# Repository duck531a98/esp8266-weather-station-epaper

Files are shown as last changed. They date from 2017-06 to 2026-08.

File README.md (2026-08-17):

# ESP8266 E-Paper Weather Station / Calendar

> [!IMPORTANT]
> ## 4.2-Inch E-Paper Calendar Hardware Project
> **PCB, BOM, enclosure, firmware attachments, and build notes:**<br>
> **[Open the 4.2-inch E-Paper Calendar on OSHWHub](https://oshwhub.com/duck/4-2-cun-mo-shui-ping-ri-li)**

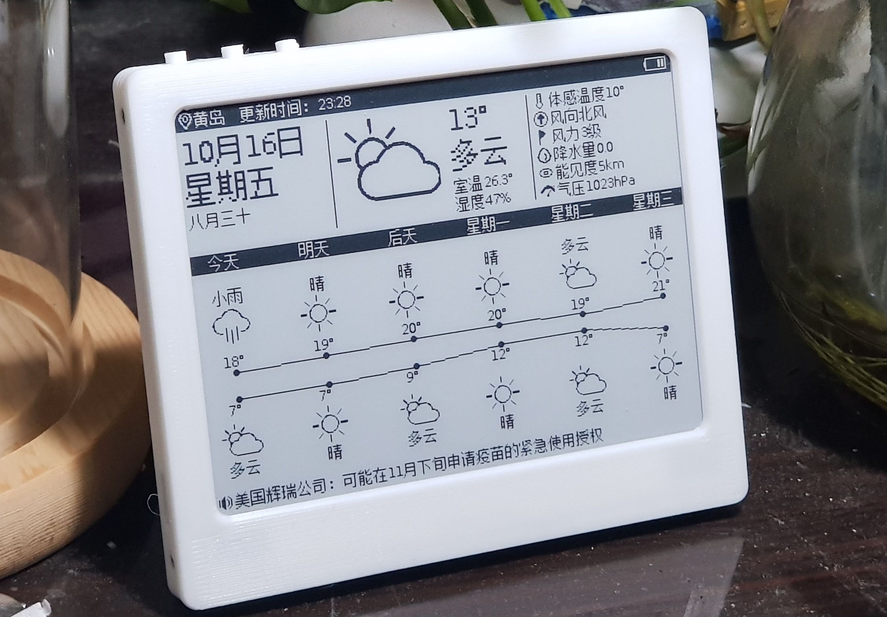
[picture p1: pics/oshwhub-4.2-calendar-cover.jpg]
4.2-inch e-paper weather calendar (https://oshwhub.com/duck/4-2-cun-mo-shui-ping-ri-li)


| 4.2-inch hardware | Multiple display sizes and layouts |
| --- | --- |
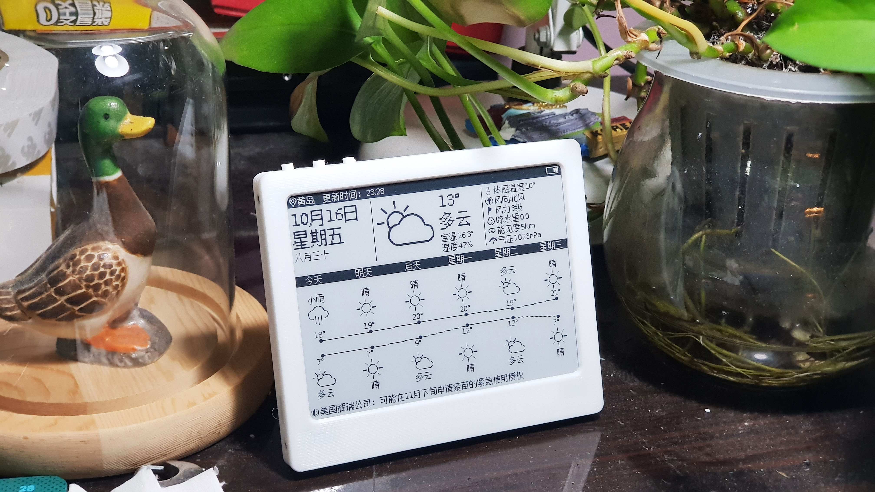
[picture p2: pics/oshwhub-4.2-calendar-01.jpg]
4.2-inch e-paper weather station
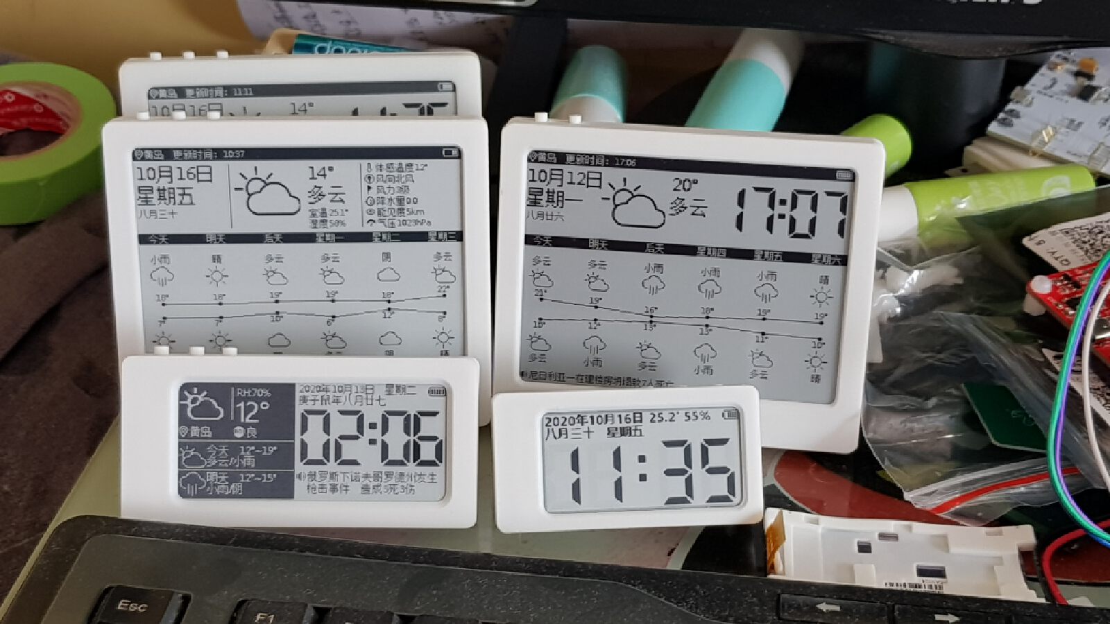
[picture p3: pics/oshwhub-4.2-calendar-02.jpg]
Multiple e-paper weather station builds
|  |  |

This repository contains the latest source code for an ESP8266 NodeMCU v2 e-paper weather station. The device can display weather forecasts, time, date, lunar-calendar information, indoor temperature and humidity, battery status, and custom messages. Partial e-paper refreshes and ESP8266 deep sleep are used to minimize average power consumption.

## Codex-Assisted Improvements

In August 2026, Codex helped review and update the networking, display, low-power, and reliability code. The main changes are:

- **Direct QWeather access:** the firmware now connects directly to QWeather. Each user can configure a personal API Host, API Key, and Location without depending on the original relay server.
- **Bounded network activity:** weather requests, network-time updates, retries, and recovery paths use timeouts and backoff so a failed network or API cannot keep the ESP8266 awake indefinitely.
- **Lower-power wake cycles:** Wi-Fi, SPI, and e-paper high-voltage power sequencing was tightened. Wake cycles that do not require networking can keep RF disabled, while failure and timed-refresh paths spend less time awake.
- **Timed partial-refresh fixes:** the WF32 clock path now preserves sub-second time across deep sleep, corrects clock drift, and separates partial refresh, panel shutdown, and sleep-to-next-minute into a bounded two-stage sequence.
- **Faster rendering:** WF32 frame transfer, framebuffer inversion, text rendering, and XBM raster composition were optimized to reduce per-pixel work, temporary strings, and unnecessary `yield()` calls.
- **Display and settings cleanup:** display paths for several 2.9, 3.2, 4.2, and 5.8-inch panels were normalized. The 4.2-inch date layout and weather-setting validation were also corrected.
- **Regression coverage:** a host-side raster test compares the optimized renderer against the original pixel renderer. All 8,208 XBM drawing cases match byte for byte. The current NodeMCU v2 firmware also compiles with Arduino IDE 1.8.9 and ESP8266 core 3.1.2.

See [`docs/PROJECT.md`](docs/PROJECT.md) for the implementation overview, build environment, and hardware-specific risks.

## Features

- Current weather and multi-day forecast
- Date, weekday, and lunar-calendar display
- Optional time display with partial refresh
- Indoor temperature and humidity display on supported hardware
- Battery-voltage indicator and low-voltage protection
- Configurable weather-update interval and active update window
- Phone-friendly local configuration portal
- Full Unicode font support through fonts stored on the device filesystem
- Custom-message display support
- Deep sleep between updates

## Hardware Projects and Community

- **Recommended 4.2-inch hardware:** [4.2-inch E-Paper Calendar on OSHWHub](https://oshwhub.com/duck/4-2-cun-mo-shui-ping-ri-li)
- **Earlier 2.9-inch PCB:** [ESP8266 E-Paper Weather Station on OSHWHub](https://oshwhub.com/duck/esp8266-weather-station-epaper)
- **Community:** QQ group 556951885

The 4.2-inch project page contains the PCB design, BOM, enclosure archive, firmware attachments, and additional build information.

## Supported Displays

The firmware contains drivers and layouts for several e-paper controllers and panel sizes. Check the manufacturer and model printed on the display flex cable before selecting a screen type in the configuration portal.

- 2.9-inch HINK, WF, DKE, and WFT0000BZ03 variants
- 3.2-inch WF32
- 4.2-inch HINK/OPM, DKE, and WF variants
- 5.8-inch WF58

Waveshare and Good Display sell modules, but the underlying panel may be produced by HINK, WF, DKE, OPM, or another manufacturer. The flex-cable marking is more useful than the module brand when choosing a driver.

## Basic Hardware

1. A supported e-paper panel
2. ESP8266 NodeMCU/Wemos board or the integrated PCB from the hardware project
3. Li-Po battery
4. Low-quiescent-current 3.3 V regulator for battery-powered builds
5. Enclosure appropriate for the selected display size

NodeMCU development boards commonly include an AMS1117 regulator and CP2102 USB-to-serial converter. Their combined quiescent current is too high for an efficient long-term battery build. Use the integrated PCB or another low-power design when battery life matters.

## Display Wiring

| E-Paper Signal | ESP8266 GPIO |
| --- | ---: |
| BUSY | GPIO4 |
| RST | GPIO2 |
| DC | GPIO5 |
| CS | GPIO15 |
| CLK | GPIO14 |
| DIN | GPIO13 |

Connect ESP8266 GPIO16 to RST so the internal deep-sleep timer can wake the chip.

## Build and Upload

- Main sketch: `WeatherStation-epaper-remote.ino`
- Target: ESP8266 NodeMCU v2
- Verified toolchain: Arduino IDE 1.8.9 with ESP8266 core 3.1.2
- Existing build parameters: `.build/build.options.json` in the development workspace

Compile and upload the main sketch with the verified ESP8266 toolchain. Upload the required files from `data/` to the ESP8266 filesystem using a filesystem uploader compatible with ESP8266 core 3.1.2.

The upstream ESP8266 Arduino documentation is available at:

- [ESP8266 Arduino core](https://github.com/esp8266/Arduino)
- [ESP8266 filesystem documentation](https://arduino-esp8266.readthedocs.io/en/latest/filesystem.html)

## Device Configuration

When configuration mode is active, connect a phone or computer to the `Epaper Weather Station` access point and open `http://192.168.4.1/`.

Configure at least:

- Wi-Fi SSID and password
- QWeather API Host
- QWeather API Key
- City or location
- E-paper panel type
- Time-display option
- Weather-update interval and active update window

Wi-Fi credentials and the QWeather API Key are stored on the device. Do not add credentials or generated configuration files to this repository.

## Weather Data

The current firmware connects directly to QWeather over HTTPS. It performs location lookup, current-weather, multi-day forecast, and air-quality requests using the credentials entered in the device portal.

DNS, connection, header, and body reads are bounded. RTC-backed retry state prevents repeated API or network failures from causing long high-power wake cycles.

## Fonts and Localization

The firmware converts UTF-8 strings to Unicode code points for display with `DrawUTF`. Font files are stored in the ESP8266 filesystem. A complete 16-by-16 Unicode font can consume about 2 MB, so builds that need only a limited character set should generate a smaller font.

The original font-generation project is available at [duck531a98/font-generator](https://github.com/duck531a98/font-generator).

## Custom Messages

The firmware retains custom-message display support. The original public relay is no longer included in this repository, so this feature requires a compatible service under your control.

## Low-Power Notes

- Deep-sleep current depends heavily on the regulator, USB-to-serial converter, pull-ups, sensors, and e-paper power circuit used by the hardware.
- E-paper BUSY waits and high-voltage shutdown paths must remain bounded to prevent a failed panel from draining the battery.
- Software time advances across deep sleep using planned sleep duration and is resynchronized during network-enabled wake cycles.
- Weather-only operation can run much longer than minute-by-minute time display because it requires far fewer wake and refresh cycles.

## Changelog

### 2026-08-17

- Imported the latest firmware source code.
- Added direct personal QWeather API configuration.
- Completed the Codex-assisted reliability, rendering, timekeeping, and low-power improvements described above.
- Verified the NodeMCU v2 build and 8,208 raster regression cases.

### 2020-05-14

- Updated the online PCB version. Some older explanations and photos below may no longer represent the current firmware.

### 2015-05-28

1. Changed the voltage-divider resistors from 1 MOhm/300 kOhm to 300 kOhm/100 kOhm (R6/R7).
2. Updated the battery-voltage calculation.
3. Stopped updates and displayed a warning when battery voltage fell below 3.4 V.

Calibrate the ADC for your own board because ESP8266 ADC readings can vary significantly.

## Earlier Project Photos

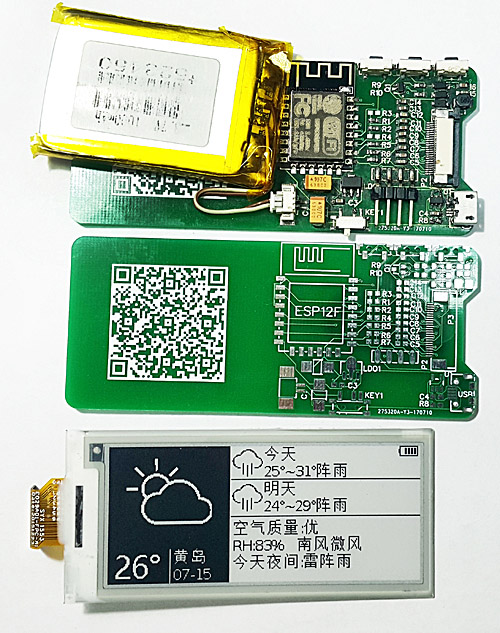
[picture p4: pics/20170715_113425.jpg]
Earlier 2.9-inch weather station


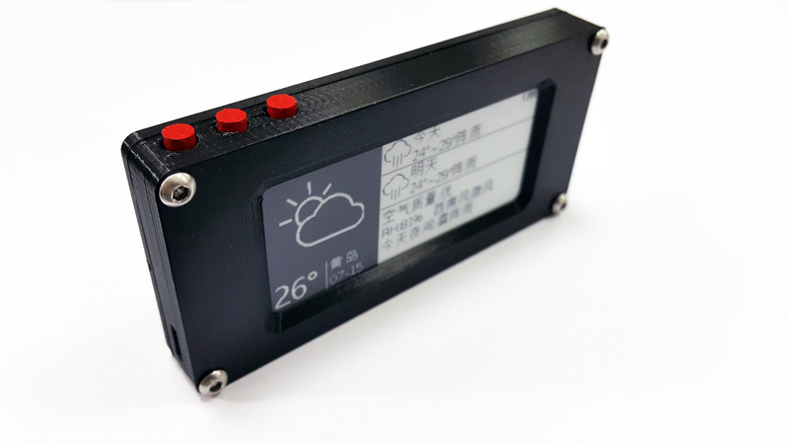
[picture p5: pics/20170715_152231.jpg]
Earlier enclosure and weather display


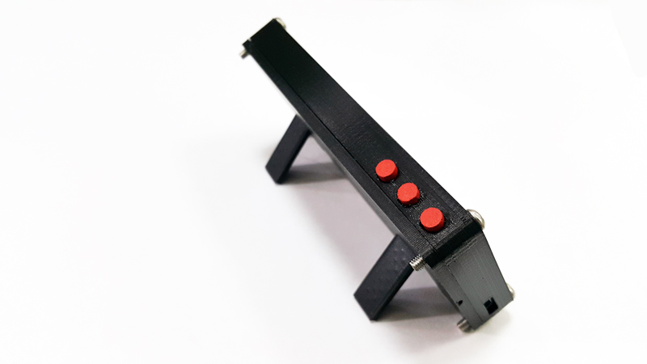
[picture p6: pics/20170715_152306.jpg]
Earlier completed build


## Credits

Thanks to Mike, Daniel, and Fred for their work on ESP8266 weather stations, JSON parsing, e-paper hardware, and the original project ecosystem.

## License

This repository is distributed under the terms in [`LICENSE`](LICENSE).

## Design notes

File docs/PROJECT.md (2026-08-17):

# WeatherStation e-paper remote

> 最后核对日期：2026-08-10

## 项目概览

这是一个运行在 ESP8266 NodeMCU v2 上的低功耗墨水屏天气站固件。设备通过 Wi-Fi 获取和风天气数据与网络时间，在支持的墨水屏上显示天气、空气质量和时间，并通过深睡降低功耗。

## 已确认的实现

- 主程序入口：`WeatherStation-epaper-remote.ino`。
- `TimeClient.cpp` 负责 NTP、HTTP Date 解析、时区换算以及跨深睡的软件时钟推进。
- `heweather.cpp` 负责和风天气网络请求与响应解析。
- `EPD_drive.cpp`、`EPD_drive_gpio.cpp` 负责多个墨水屏型号的初始化、刷新和休眠。
- 配置保存在 LittleFS 与 EEPROM 缓存中；时间、刷新阶段和退避状态使用 ESP8266 RTC 用户内存跨深睡保存。
- WF32（3.2 英寸）在显示时间时采用局刷、短深睡、屏幕关断、再睡至下一分钟的两阶段流程。

## 开发与验证

| 用途 | 方法 |
|---|---|
| 构建 | Arduino IDE 1.8.9 / ESP8266 core 3.1.2；复用 `.build/build.options.json` 中的 NodeMCU v2 FQBN 与库路径 |
| 测试 | `tests/epd_raster_tests.cpp` 使用旧逐点算法作为 oracle，对 XBM 帧缓冲合成做宿主端逐字节差分验证；修改固件后仍需完整编译 |
| 硬件验证 | 烧录连接的 ESP8266，观察启动串口、对应屏幕型号的局刷/全刷路径和网络校时后的显示 |

## 关键约束与风险

- ESP8266 深睡期间无法用 `millis()` 直接测量真实睡眠时长，软件时钟依赖计划睡眠时长并会产生漂移，因此联网周期必须重新校时。
- 屏幕 BUSY、刷新完成和休眠命令属于高功耗敏感路径，故障处理必须保持有界等待并尽量关闭高压电路。
- 设备配置、凭据和生成的固件不应提交到仓库。

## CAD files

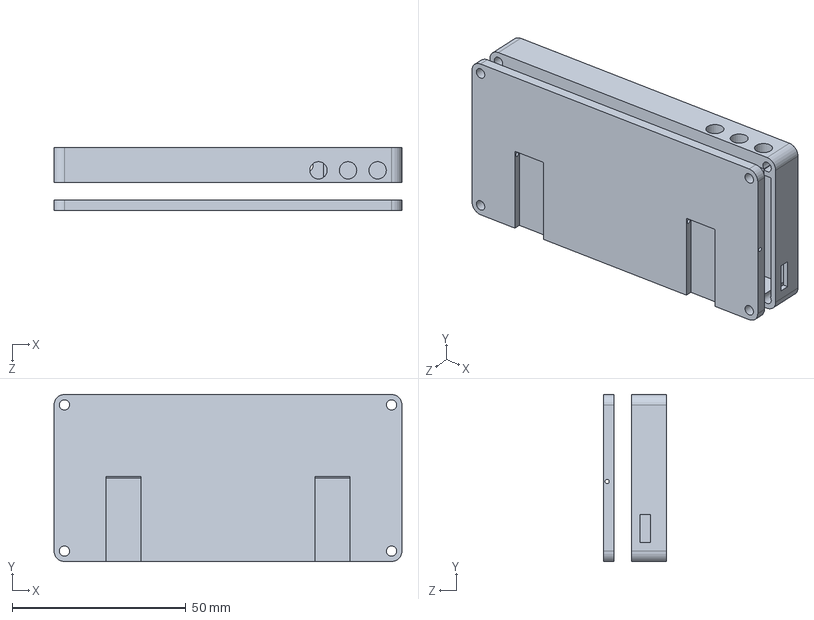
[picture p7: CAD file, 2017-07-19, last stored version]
STL/电纸屏外壳-对称-方形.SLDPRT
100.0 x 48.0 x 18.0 mm

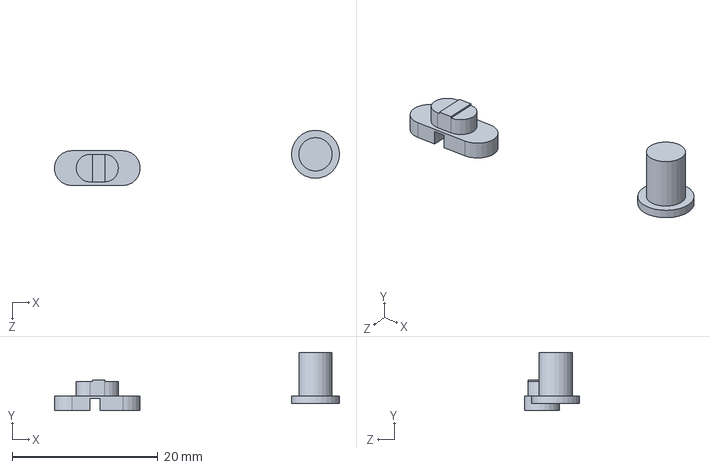
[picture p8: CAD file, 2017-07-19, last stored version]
STL/按钮.SLDPRT
39.1 x 8.00 x 7.58 mm

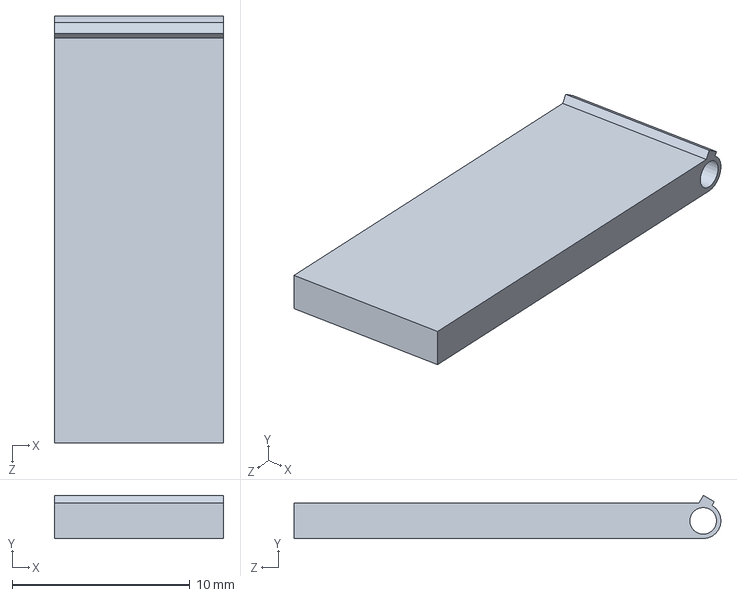
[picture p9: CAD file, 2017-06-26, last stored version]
STL/后支架.SLDPRT
9.50 x 2.43 x 24.0 mm

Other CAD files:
STL/后支架.STL
STL/按钮.STL
STL/电纸屏外壳-对称-方形.STL

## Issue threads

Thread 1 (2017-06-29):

ePaper Library

mattncsu, 2017-06-29:
Hi! I got the sketch working pretty quickly on my ESP & Waveshare 2.9" board.  Very cool! Did you write the library for the epd? It is substantially better than the one Waveshare provides on their website.  If so, could you publish it as a standalone library, I've tried merging your EPD_drive.cpp/.h with the ones from the Waveshare demo without much luck since I'm still new to cpp.

Thanks!

duck531a98, 2017-06-29:
Waveshare library display strings with part refresh, stores font in header file.
My library write all strings and pictures into buffer and refresh the display once, stores font in spiff.
so they can't work together. even though you merge them, you can only use one method to refresh the display.

mattncsu, 2017-06-29:
Thanks for the tip! I like the buffer approach much better than what was in the demo code.   What do you think is the best way to display text rotated 90°?  [This epaper library for the ESP32](https://github.com/loboris/ESP32_ePaper_example) supports arbitrary rotation but I don't know how to adapt the code to work with Arduino

duck531a98, 2017-06-30:
Add some simple codes to transform the coordinates when operating the buffer to  change the direction of text.  if you can't handle that, you can wait for some days, i will do that.

mattncsu, 2017-07-02:
I can give it a try but pretty new to cpp so it may be ugly!

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

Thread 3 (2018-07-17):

字符显示乱码

jcyfkimi, 2018-07-17:
我将data目录下的文件烧录进spi flash后，显示乱码，无论是中文还是英文，我尝试着将从flash读取的内容打印出来，不过有点不明白这个字体是如何转换的。望解答。

duck531a98, 2018-07-17:
你好，你要确保data目录下的文件都已经写入spiff中，可以试着看一下spiff中的文件列表。如果文件存在，是不会出现乱码问题的。字体的转换方法可以看看我字体转换工具的源码。

jcyfkimi, 2018-07-18:
这个spiffs烧写很奇怪，一开始烧，文件都存在，就是各种乱码，然后我format了一遍，再烧，文件少了icon80，字符显示正常了，再烧一次，文件和现实都正常了。挺奇怪的。

duck531a98, 2018-07-20:
我觉得是线接触不好吧

jcyfkimi, 2018-07-26:
恩，有点奇怪，不过好在目前搞定了，现在的问题是，heweather的api改到了v6，看你原来一次连接就能拿全的信息，现在得分多次，分了多次后，虽然信息能拿到了，但是要在送给epd显示的时候确显示不出来了，连清屏都不行。

duck531a98, 2018-07-27:
一次跟多次一样的，一次拿全的信息也是分别写入显示缓存最后一次性送到屏幕，不要每更新一点就送到屏幕，太快反应不过来。支持的字符串编码是utf-8。

38293312, 2018-08-19:
I also encountered the same problem

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

jcyfkimi, 2018-08-21:
you can use below code to check if the data file are written into the spi
flash on setup function. Make sure all the files are exists.

void check_res_from_spiffs()
{
  SPIFFS.begin();
  File file;
  FSInfo fs_info;
  SPIFFS.info(fs_info);
  Serial.println("Before format:");
  Serial.print("totalBytes=");
  Serial.println(fs_info.totalBytes, DEC);
  Serial.print("usedBytes=");
  Serial.println(fs_info.usedBytes, DEC);
  Serial.print("blockSize=");
  Serial.println(fs_info.blockSize, DEC);
  Serial.print("pageSize=");
  Serial.println(fs_info.pageSize, DEC);
  Serial.print("maxOpenFiles=");
  Serial.println(fs_info.maxOpenFiles, DEC);
  Serial.print("maxPathLength=");
  Serial.println(fs_info.maxPathLength, DEC);
  if (SPIFFS.exists("/font10"))
  {
    Serial.print("font10 exists, size = ");
    file = SPIFFS.open("/font10", "r");
    Serial.println(file.size());
    file.close();
  }
  if (SPIFFS.exists("/font12"))
  {
    Serial.print("font12 exists, size = ");
    file = SPIFFS.open("/font12", "r");
    Serial.println(file.size());
    file.close();
  }
  if (SPIFFS.exists("/font32"))
  {
    Serial.print("font32 exists, size = ");
    file = SPIFFS.open("/font32", "r");
    Serial.println(file.size());
    file.close();
  }
  if (SPIFFS.exists("/weathericon"))
  {
    Serial.print("weathericon exists, size = ");
    file = SPIFFS.open("/weathericon", "r");
    Serial.println(file.size());
    file.close();
  }
  if (SPIFFS.exists("/weathericon32"))
  {
    Serial.print("weathericon32 exists, size = ");
    file = SPIFFS.open("/weathericon32", "r");
    Serial.println(file.size());
    file.close();
  }
  if (SPIFFS.exists("/weathericon80"))
  {
    Serial.print("weathericon80 exists, size = ");
    file = SPIFFS.open("/weathericon80", "r");
    Serial.println(file.size());
    file.close();
  }
  SPIFFS.end();
}

38293312 <notifications@github.com> 于2018年8月19日周日 下午9:09写道：

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

38293312, 2018-08-21:
问题解决了，现在发现和你照片界面不一样，而且更新参数修改以后，从串口查看没有参数，如果按复位键更本没有有参数到屏上，简单来说就是不能启动。

jcyfkimi, 2018-08-21:
heweather的api换了，博主的php还是使用V5的API，新注册的用户已经不让用了，所以没有数据，现在是V6，很多API都修改了，没有办法一次拿全数据，具体就去看heweather的官方文档吧，我最近没时间来弄这个。

38293312 <notifications@github.com> 于 2018年8月21日周二 15:48写道：

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

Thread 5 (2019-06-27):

arduinoIDE编译报错

irongu, 2019-06-27:
Arduino:1.8.9 (Windows 8.1), 开发板："Generic ESP8266 Module, 80 MHz, Flash, Disabled, none, 26 MHz, 40MHz, QIO (fast), 4M (3M SPIFFS), 2, v2 Lower Memory, Disabled, None, Only Sketch, 115200"

sketch\TimeClient.cpp: In member function 'long int TimeClient::getCurrentEpochWithUtcOffset()':

TimeClient.cpp:140:67: error: invalid operands of types 'double' and 'long int' to binary 'operator%'

   return round(getCurrentEpoch() + 3600 * myUtcOffset + 86400L) % 86400L;

                                                                   ^

exit status 1
invalid operands of types 'double' and 'long int' to binary 'operator%'

irongu, 2019-06-28:
程序运行路径改为全英文，开发板选项改为nodemcu1.0之后解决

Closed 2019-06-28.

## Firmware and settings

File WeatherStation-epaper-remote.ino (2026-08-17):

/**
GPL v3.0
Copyright (c) 2017 by Hui Lu
*/

#include <ESP8266WiFi.h>
#include "Wire.h"
#include "TimeClient.h"
#include <ESP8266WebServer.h>
#include <ESP8266mDNS.h>
#include "DFRobot_SHT20.h"
#include "heweather.h"
#include <EEPROM.h>
#include <SPI.h>
#include "webpage.h"
#include "EPD_drive.h"
#include "EPD_drive_gpio.h"
//#include "EPD_drive_gpio.cpp"
#include "bitmaps.h"
#include "gray_image.h"
#include "lang.h"
#include "FS.h"
#include <LittleFS.h>
#include <ArduinoJson.h>
#include <Ticker.h>
#define ADC_ON digitalWrite(12,1);
#define ADC_OFF digitalWrite(12,0);
//#define debug 1 ///< 调试模式，打开串口输出
#define SDA 13
#define SCL 14
//#define FAST_MODE
ADC_MODE(0);
/***************************
  全局设置  
 **************************/
bool first_run=false;
bool exit_portal=0;
String wifi_ssid;
String wifi_password;
int epd_time=1200;//局刷耗时ms
String epd_type;
byte epd_type_index;
byte contrast=0x15;
String qweather_host;
String qweather_api_key;
String qweather_location_id;
String qweather_location_name;
String qweather_air_coordinates;
int crc;
String update_time_range;
byte showtime=0;            ///< 是否显示时间，不支持局刷的屏不要开
int sleeptime=60;    ///< 更新天气的间隔 单位为分钟,间隔是下面更新时间的间隔的整数倍如更新时间间隔为30分钟，更新天气间隔须为30分钟的倍数，不能是31，43分钟这样
int timeupdateinterval=1*60;  ///< 更新时间的间隔，单位为秒（显示时间时不可更改，只显示天气可改为60*30）
const float UTC_OFFSET = 8; ///< 中国标准时间 UTC+8
byte end_time=23;           ///< 停止更新天气的时间 23：00
byte start_time=0;          ///< 开始更新天气的时间 7：00
 /***************************
  **************************/
String city;
String lastUpdate = "--";
bool shouldsave=false;
bool config_ready=false;
bool epdModelTrusted=false;
uint32_t eepromQWeatherConfigHash=0;
bool eepromQWeatherConfigHashValid=false;
TimeClient timeClient(UTC_OFFSET);
Duck_EPD EPD = Duck_EPD();
heweatherclient heweather(lang);
ESP8266WebServer web(80);
StaticJsonDocument<1536> doc;
DFRobot_SHT20 sht20;
File uploadFile;
const size_t PHOTO_UPLOAD_BYTES=400UL*300UL/2UL;
const size_t PHOTO_UPLOAD_REQUEST_MAX=PHOTO_UPLOAD_BYTES+4096UL;
const char PHOTO_UPLOAD_PATH[]="/pic.xbm";
const char PHOTO_UPLOAD_TEMP_PATH[]="/pic.tmp";
size_t uploadBytesReceived=0;
int uploadResponseStatus=400;
const char* uploadResponseMessage="未收到图片";
bool uploadSucceeded=false;
bool pictureDisplayPending=false;
bool epdSpiActive=false;
bool permanentSleepAfterDisplay=false;
#ifdef POWER_TEST_FORCE_WEATHER
bool powerTestSecondWeatherPending=false;
#endif
const uint32_t EPD_SPI_CLOCK_HZ=20000000UL;
const unsigned long PORTAL_TIMEOUT_MS=5UL*60UL*1000UL;
const unsigned long WIFI_CONNECT_BUDGET_MS=10000UL;
const unsigned long WIFI_FAST_CONNECT_MS=2500UL;
const unsigned long WF32_WAKE_BUDGET_MS=45000UL;
const unsigned long DEFAULT_WAKE_BUDGET_MS=75000UL;
const unsigned long FAILURE_BACKOFF_SECONDS=60UL*60UL;
const float CRITICAL_BATTERY_VOLTAGE=3.55f;
const uint32_t WIFI_CACHE_RTC_OFFSET=32;
const uint32_t WIFI_CACHE_MAGIC=0x57464331UL; // "WFC1"
const uint32_t BATTERY_BACKOFF_RTC_OFFSET=37;
const uint32_t BATTERY_BACKOFF_MAGIC=0x42415431UL; // "BAT1"
const uint32_t PORTAL_RESTART_RTC_OFFSET=38;
const uint32_t PORTAL_RESTART_MAGIC=0x41503131UL; // "AP11"
const uint32_t PORTAL_ATTEMPT_RTC_OFFSET=39;
const uint32_t PORTAL_ATTEMPT_MAGIC=0x41505431UL; // "APT1"
const uint32_t QWEATHER_BACKOFF_RTC_OFFSET=40;
const uint32_t QWEATHER_BACKOFF_MAGIC=0x51574231UL; // "QWB1"
const uint32_t AIR_BACKOFF_RTC_OFFSET=45;
const uint32_t AIR_BACKOFF_MAGIC=0x41514231UL; // "AQB1"
const uint32_t MAX_QWEATHER_BACKOFF_SECONDS=24UL*60UL*60UL;
const uint32_t AIR_RETRY_BACKOFF_SECONDS=6UL*60UL*60UL;
const byte MAX_QWEATHER_BACKOFF_FAILURES=10;
const uint32_t PERMANENT_SLEEP_RTC_OFFSET=4;
const uint32_t PERMANENT_SLEEP_MAGIC=0x534c5031UL; // "SLP1"
const uint32_t UNIX_TIME_RTC_OFFSET=16;
const uint32_t LEGACY_UNIX_TIME_RTC_MAGIC=0x554e4958UL; // "UNIX"
const uint32_t UNIX_TIME_RTC_MAGIC=0x554d5332UL; // "UMS2"
const byte EEPROM_CACHE_MAGIC=0x57;
// Bump this together with QWEATHER_CONFIG_HASH_SCHEMA. Version 2 adds the
// QWeather configuration hash at bytes 12..15 for the EEPROM-only wake path.
const byte EEPROM_CACHE_VERSION=2;
const byte QWEATHER_CONFIG_HASH_SCHEMA=2;
const byte EEPROM_QWEATHER_HASH_ADDRESS=12;
const byte RTC_SCHEDULE_MAGIC=126;
const byte RTC_SCHEDULE_CHECK_SEED=0xa7;
const byte BATTERY_STATE_OK=0;
const byte BATTERY_STATE_CRITICAL=1;
const byte BATTERY_STATE_IMPLAUSIBLE=2;
Ticker wakeDeadlineTimer;
volatile bool wakeDeadlineExpired=false;

struct WiFiQuickConnectCache
{
  uint32_t magic;
  uint32_t ssidHash;
  byte channel;
  byte bssid[6];
  byte reserved;
  uint32_t checksum;
};

struct UnixTimeRtcCache
{
  uint32_t magic;
  uint32_t epoch;
  uint32_t milliseconds;
  uint32_t checksum;
};

struct LegacyUnixTimeRtcCache
{
  uint32_t magic;
  uint32_t epoch;
  uint32_t checksum;
};

struct QWeatherBackoffCache
{
  uint32_t magic;
  uint32_t configHash;
  uint32_t retryNotBefore;
  uint16_t failureCount;
  byte failureClass;
  byte reserved;
  uint32_t checksum;
};

struct AirBackoffCache
{
  uint32_t magic;
  uint32_t configHash;
  uint32_t retryNotBefore;
  uint32_t checksum;
};

static_assert(sizeof(UnixTimeRtcCache)%4==0,
               "Unix RTC cache must remain 4-byte aligned");
static_assert(UNIX_TIME_RTC_OFFSET+sizeof(UnixTimeRtcCache)/4<=
                WIFI_CACHE_RTC_OFFSET,
              "Unix RTC cache overlaps the WiFi cache");
static_assert(sizeof(WiFiQuickConnectCache)==20,
              "WiFi RTC cache must remain 4-byte aligned");
static_assert(WIFI_CACHE_RTC_OFFSET+sizeof(WiFiQuickConnectCache)/4==
              BATTERY_BACKOFF_RTC_OFFSET,
              "WiFi RTC cache overlaps the backoff markers");
static_assert(PORTAL_RESTART_RTC_OFFSET+1==PORTAL_ATTEMPT_RTC_OFFSET,
              "Portal RTC markers must not overlap");
static_assert(PORTAL_ATTEMPT_RTC_OFFSET+1==QWEATHER_BACKOFF_RTC_OFFSET,
              "Weather backoff must follow portal markers");
static_assert(sizeof(QWeatherBackoffCache)==20,
              "Weather backoff cache must remain 4-byte aligned");
static_assert(QWEATHER_BACKOFF_RTC_OFFSET+
                sizeof(QWeatherBackoffCache)/sizeof(uint32_t)==
              AIR_BACKOFF_RTC_OFFSET,
              "Air backoff must follow weather backoff");
static_assert(sizeof(AirBackoffCache)==16,
              "Air backoff cache must remain 4-byte aligned");
static_assert(AIR_BACKOFF_RTC_OFFSET+
                sizeof(AirBackoffCache)/sizeof(uint32_t)<=128,
              "Backoff caches exceed RTC user memory");
bool loadWiFiQuickConnectCache(WiFiQuickConnectCache& cache);
void sleepAfterPowerFault();
uint32_t qweatherBackoffChecksum(const QWeatherBackoffCache& cache);
bool readQWeatherBackoff(QWeatherBackoffCache& cache);
uint32_t airBackoffChecksum(const AirBackoffCache& cache);
bool readAirBackoff(AirBackoffCache& cache);
bool qweatherBackoffWasLoaded=false;

void beginEpdSpi()
{
  if(epdSpiActive) return;
  SPI.begin();
  // HSPI 会把 GPIO12 配成 MISO；本板用它控制 ADC/传感器电源，
  // 屏幕只写不读，因此立即恢复为低电平输出。
  pinMode(12,OUTPUT);
  ADC_OFF;
  SPI.beginTransaction(SPISettings(EPD_SPI_CLOCK_HZ,MSBFIRST,SPI_MODE0));
  HARDWARE_SPI=1;
  epdSpiActive=true;
}

void endEpdSpi()
{
  if(!epdSpiActive) return;
  HARDWARE_SPI=0;
  SPI.endTransaction();
  SPI.end();
  epdSpiActive=false;
}

void stopWiFiRadio()
{
  WiFi.setAutoReconnect(false);
  WiFi.setAutoConnect(false);
  WiFi.disconnect(false);
  WiFi.mode(WIFI_OFF);
  delay(1);
}

uint32_t fnv1a(const byte* data,size_t length,uint32_t hash)
{
  for(size_t i=0;i<length;i++)
  {
    hash^=data[i];
    hash*=16777619UL;
  }
  return hash;
}

uint32_t hashString(const String& value)
{
  return fnv1a((const byte*)value.c_str(),value.length(),2166136261UL);
}

uint32_t currentQWeatherConfigHash()
{
  uint32_t hash=2166136261UL;
  const byte separator=0;
  hash=fnv1a(&QWEATHER_CONFIG_HASH_SCHEMA,1,hash);
  hash=fnv1a((const byte*)qweather_host.c_str(),qweather_host.length(),hash);
  hash=fnv1a(&separator,1,hash);
  hash=fnv1a((const byte*)qweather_api_key.c_str(),
             qweather_api_key.length(),hash);
  hash=fnv1a(&separator,1,hash);
  hash=fnv1a((const byte*)city.c_str(),city.length(),hash);
  return fnv1a(&separator,1,hash);
}

uint32_t readEepromQWeatherConfigHash()
{
  uint32_t hash=0;
  for(byte index=0;index<sizeof(hash);index++)
    hash|=(uint32_t)EEPROM.read(EEPROM_QWEATHER_HASH_ADDRESS+index)
          <<(index*8);
  return hash;
}

void writeEepromQWeatherConfigHash(uint32_t hash)
{
  for(byte index=0;index<sizeof(hash);index++)
    EEPROM.write(EEPROM_QWEATHER_HASH_ADDRESS+index,
                 (byte)(hash>>(index*8)));
}

bool availableQWeatherConfigHash(uint32_t& hash)
{
  if(config_ready)
  {
    hash=currentQWeatherConfigHash();
    return true;
  }
  if(eepromQWeatherConfigHashValid)
  {
    hash=eepromQWeatherConfigHash;
    return true;
  }
  return false;
}

uint32_t qweatherBackoffChecksum(const QWeatherBackoffCache& cache)
{
  return fnv1a((const byte*)&cache,
               offsetof(QWeatherBackoffCache,checksum),2166136261UL);
}

bool readQWeatherBackoff(QWeatherBackoffCache& cache)
{
  memset(&cache,0,sizeof(cache));
  uint32_t magic=0;
  if(!ESP.rtcUserMemoryRead(QWEATHER_BACKOFF_RTC_OFFSET,
                            &magic,sizeof(magic))||
     magic!=QWEATHER_BACKOFF_MAGIC)
    return false;
  if(!ESP.rtcUserMemoryRead(QWEATHER_BACKOFF_RTC_OFFSET,
                            (uint32_t*)&cache,sizeof(cache))||
     cache.magic!=QWEATHER_BACKOFF_MAGIC||
     cache.failureCount==0||
     cache.failureCount>MAX_QWEATHER_BACKOFF_FAILURES||
     cache.reserved!=0||
     cache.failureClass<
       (byte)heweatherclient::FailureClass::Transient||
     cache.failureClass>
       (byte)heweatherclient::FailureClass::Permanent||
     cache.checksum!=qweatherBackoffChecksum(cache))
    return false;
  return true;
}

void clearQWeatherBackoff()
{
  uint32_t clearedMagic=0;
  ESP.rtcUserMemoryWrite(QWEATHER_BACKOFF_RTC_OFFSET,
                         &clearedMagic,sizeof(clearedMagic));
  qweatherBackoffWasLoaded=false;
}

bool qweatherBackoffDefersRequest()
{
  qweatherBackoffWasLoaded=false;
  QWeatherBackoffCache cache;
  if(!readQWeatherBackoff(cache)) return false;
  uint32_t configHash=0;
  if(availableQWeatherConfigHash(configHash)&&
     cache.configHash!=configHash)
  {
    clearQWeatherBackoff();
    return false;
  }

  qweatherBackoffWasLoaded=true;
  if(cache.failureClass==
       (byte)heweatherclient::FailureClass::Configuration||
     cache.failureClass==
       (byte)heweatherclient::FailureClass::Permanent)
    return true;
  // If the clock cache was lost while a timed backoff survived, let the next
  // ordinary weather slot recover time through NTP. Keeping it deferred here
  // would leave the device RF-disabled forever because the deadline could
  // never become comparable again.
  if(!timeClient.hasValidUnixTime()) return false;
  return (int32_t)(cache.retryNotBefore-timeClient.getUnixEpoch())>0;
}

bool qweatherBackoffAllowsRadio()
{
  QWeatherBackoffCache cache;
  if(!readQWeatherBackoff(cache)) return true;
  // The ordinary time-only wake has not mounted LittleFS yet. Compare against
  // the hash already carried in its validated EEPROM cache, avoiding both a
  // filesystem mount and an unnecessary RF-disabled wake for a stale marker.
  uint32_t configHash=0;
  if(availableQWeatherConfigHash(configHash)&&
     cache.configHash!=configHash)
  {
    clearQWeatherBackoff();
    return true;
  }
  if(cache.failureClass==
       (byte)heweatherclient::FailureClass::Configuration||
     cache.failureClass==
       (byte)heweatherclient::FailureClass::Permanent)
    return false;
  // A timed marker without a trusted clock must allow one normal scheduled
  // RF wake so updateData() can restore Unix time through NTP.
  if(!timeClient.hasValidUnixTime()) return true;
  // Callers advance time to the next wake before asking, so this comparison
  // selects RF for that next boot, exactly matching deepSleepInstant semantics.
  return (int32_t)(cache.retryNotBefore-timeClient.getUnixEpoch())<=0;
}
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
void loop() {
 
    
    if(!heweather.timeout||first_run) sleepEpdOrBackoff();
    if(permanentSleepAfterDisplay)
    {
      #ifdef debug
      Serial.println("Low-battery page complete; entering permanent sleep");
      #endif
      enterPermanentDeepSleep();
      return;
    }
    #ifdef POWER_TEST_FORCE_WEATHER
    if(powerTestSecondWeatherPending)
    {
      powerTestSecondWeatherPending=false;
      forceWeatherUpdateNextBoot();
      timeClient.advanceMilliseconds(3000UL);
      write_time_to_rtc_mem();
      #ifdef debug
      Serial.println("Power test: deep-sleeping 3s for RTC WiFi cache check");
      #endif
      ESP.deepSleepInstant(3000000ULL,WAKE_RF_DEFAULT);
      return;
    }
    #endif
    if(showtime==1)
    {
      byte seconds=timeClient.getSeconds_byte();
      if(seconds>58) timeupdateinterval=60-seconds+60;
      else timeupdateinterval=60-seconds;     
      //timeupdateinterval=1;//暴力测试 
    }
    timeClient.advanceMilliseconds((uint32_t)timeupdateinterval*1000UL);
    //timeClient.localEpoc+=60*1000;//暴力测试
    write_time_to_rtc_mem();//save time before sleeping}
    #ifdef debug
     Serial.printf("Finish at %dms\n",millis());
    #endif
    
    // Match the RF option to what the *next* wake will do. In particular,
    // configurations whose weather interval equals the sleep interval need RF
    // immediately; WAKE_RF_DISABLED cannot be reversed after boot.
    RFMode nextWakeMode=nextWakeNeedsRadio()?WAKE_RF_DEFAULT:
                                               WAKE_RF_DISABLED;
    // All active hardware has been shut down above. Avoid the SDK's deferred
    // WiFi shutdown while preserving nextWakeMode for the following boot.
    ESP.deepSleepInstant((uint64_t)timeupdateinterval*1000000ULL,
                         nextWakeMode);
    //ESP.deepSleep(1 * 1 * 1000000,WAKE_RF_DISABLED); //暴力测试

}
void updatedisplay()
{
  // Keep the last valid e-paper image on routine network failures. This saves
  // an unnecessary refresh and guarantees that no error branch powers a panel
  // which is then left awake while the ESP sleeps.
  if(heweather.timeout&&!first_run)
  {
    #ifdef debug
    Serial.println("Weather failed; keeping previous display");
    #endif
    return;
  }

  bool sht20_found=false;
  bool sht30_found=false;
  float Hum=NAN,Temp=NAN;
  if(!heweather.timeout)
  {
    endEpdSpi();
    pinMode(12,OUTPUT);
    ADC_OFF;
    pinMode(SDA,OUTPUT);
    pinMode(SCL,OUTPUT);
    digitalWrite(SDA,LOW);
    digitalWrite(SCL,LOW);
    delay(20);
    ADC_ON;
    delay(50);
    Wire.begin(SDA,SCL);
    Wire.setClock(100000);

    // 优先读取更快的 SHT31；成功后不再重复访问 SHT20。
    for(byte attempt=0;attempt<2&&!sht30_found;attempt++)
    {
      Wire.beginTransmission(0x44);
      byte error=Wire.endTransmission();
      #ifdef debug
      Serial.printf("SHT31 i2c error=%d\n",error);
      #endif
      if(error==0)
      {
        float candidateHum=NAN;
        float candidateTemp=NAN;
        if(readSht31(candidateTemp,candidateHum))
        {
          Hum=candidateHum;
          Temp=candidateTemp;
          sht30_found=true;
        }
      }
    }

    if(!sht30_found)
    {
      for(byte attempt=0;attempt<2&&!sht20_found;attempt++)
      {
        Wire.beginTransmission(0x40);
        byte error=Wire.endTransmission();
        #ifdef debug
        Serial.printf("SHT20 i2c error=%d\n",error);
        #endif
        if(error!=0) continue;

        // DFRobot_SHT20 stores the TwoWire pointer only in initSHT20().
        // Without this call an attached 0x40 sensor dereferences nullptr and
        // can create a high-drain exception reboot loop.
        sht20.initSHT20(Wire);
        Wire.setClock(100000);
        float candidateHum=sht20.readHumidity();
        float candidateTemp=sht20.readTemperature();
        if(!isnan(candidateHum)&&!isnan(candidateTemp)&&
           candidateHum>=0.0f&&candidateHum<=100.0f&&
           candidateTemp>=-45.0f&&candidateTemp<=130.0f)
        {
          Hum=candidateHum;
          Temp=candidateTemp;
          sht20_found=true;
        }
      }
    }

    #ifdef debug
    Serial.printf("hum=%ftemp=%f\n",Hum,Temp);
    #endif
    ADC_OFF;
  }

  beginEpdSpi();
  EPD.clearbuffer();
  #ifdef debug
  Serial.printf("Weather frame render begin at %lums\n",millis());
  #endif
  if(heweather.citystr=="null") heweather.citystr="未知城市,请重新设置";
    if(showtime==1){
    if(EPD.EPD_Type==WX29||EPD.EPD_Type==WF29||EPD.EPD_Type==DKE29_3COLOR||EPD.EPD_Type==WF29BZ03)
    {
      if(heweather.timeout==false)
     {
          EPD.fontscale=1;    
          EPD.SetFont(ICON50); 
          EPD.DrawUTF(0,0,String(char(heweather.getMeteoconIcon(heweather.now_cond_index.toInt()))));
        
          EPD.SetFont(FONT12);//今天天气
          byte x1=68,y1=0;
          EPD.DrawUTF(x1,y1+32,(String)todaystr+" "+heweather.today_tmp_min+"°~"+heweather.today_tmp_max+"°");
          EPD.DrawUTF(x1+12,y1+32,heweather.today_txt_d+"/"+heweather.today_txt_n);
          EPD.SetFont(ICON32);
          unsigned char code2[]={0x00,heweather.getMeteoconIcon(heweather.today_cond_d_index.toInt())};
          EPD.DrawUnicodeChar(x1-3,y1,32,32,code2);
          EPD.DrawXline(0,125,63);
        
          EPD.SetFont(FONT12);//明天天气
          byte x2=98,y2=0;
          EPD.DrawUTF(x2,y2+32,(String)tomorrowstr+" "+heweather.tomorrow_tmp_min+"°~"+heweather.tomorrow_tmp_max+"°");
          EPD.DrawUTF(x2+12,y2+32,heweather.tomorrow_txt_d+"/"+heweather.tomorrow_txt_n);
          EPD.SetFont(ICON32);
          unsigned char code3[]={0x00,heweather.getMeteoconIcon(heweather.tomorrow_cond_d_index.toInt())};
          EPD.DrawUnicodeChar(x2-3,y2,32,32,code3);
          EPD.DrawXline(0,125,95);
         
        
          EPD.SetFont(FONT12);
          EPD.DrawXbm_P(48,0,12,12,(unsigned char *)city_icon);//位置图标
          EPD.DrawUTF(48,13,heweather.citystr);//城市名
          EPD.DrawXbm_P(48,60,12,12,(unsigned char *)aqi_icon);
          EPD.DrawUTF(48,74,heweather.qlty);//空气质量
      
         // EPD.DrawUTF(5,63,"RH:"+heweather.now_hum+"%");//湿度
          EPD.DrawUTF(0,130,heweather.year);//日期
          EPD.DrawUTF(12,130,heweather.nongli);//农历
          EPD.DrawXbm_P(96,128,12,12,(unsigned char *)message);
          EPD.DrawUTF(96,140,heweather.message);//消息
      
          EPD.DrawXbm_P(24,132,35,72,digi_num[timeClient.getHours()[0]-0x30]);
          EPD.DrawXbm_P(24,169,35,72,digi_num[timeClient.getHours()[1]-0x30]);
          EPD.DrawXbm_P(24,206,35,72,digi_num[10]);
          EPD.DrawXbm_P(24,220,35,72,digi_num[timeClient.getMinutes()[0]-0x30]);
          EPD.DrawXbm_P(24,255,35,72,digi_num[timeClient.getMinutes()[1]-0x30]);
          if(EPD.EPD_Type==WF29BZ03)
          {
          write_last_time(timeClient.getHours()[0],timeClient.getHours()[1],timeClient.getMinutes()[0],timeClient.getMinutes()[1]);
          }
             if(sht30_found==true||sht20_found==true)
            {
              EPD.DrawUTF(1,63,"室外");  EPD.DrawUTF(1,96,"室内");
              EPD.DrawUTF(16,63,heweather.now_tmp+"°");//天气实况温度
              EPD.DrawUTF(16,96,String(Temp,1)+"°");//室内温度
              EPD.DrawUTF(28,63,heweather.now_hum+"%");
              EPD.DrawUTF(28,96,String(Hum,0)+"%");//室内湿度
              EPD.DrawYline(5,40,58);EPD.DrawYline(5,40,90);
              }
            else
            {
              EPD.DrawUTF(5,63,"RH:"+heweather.now_hum+"%");
              EPD.SetFont(FONT32);
              EPD.DrawUTF(16,60,heweather.now_tmp+"°");//天气实况温度
              EPD.DrawYline(5,40,58);
              }
          
          EPD.Inverse(0,127,0,127);
          dis_batt(3,272);//电量显示
        }
        else
        {
                 if(first_run==true)
                     {
                      EPD.EPD_init_Full();
                      EPD.clearbuffer();
                      EPD.fontscale=2;
                      EPD.SetFont(FONT12); 
                      EPD.EPD_Set_Contrast(contrast);
                      EPD.DrawUTF(16,0,"和风天气请求超时");
                      EPD.DrawUTF(50,0,"检查网络连接或按左侧EN键重试");
                      EPD.EPD_Dis_Full((unsigned char *)EPD.EPDbuffer,1);
                     }          
          
          }
    }
    else  if(EPD.EPD_Type==OPM42||EPD.EPD_Type==DKE42_3COLOR||EPD.EPD_Type==WF58||EPD.EPD_Type==WF42)
    {
      if(heweather.timeout==false)
      {
      EPD.fontscale=1;
      EPD.SetFont(FONT12); 
      EPD.DrawXbm_P(2,2,12,12,(unsigned char *)city_icon);
      EPD.DrawUTF(2,14,heweather.citystr+" 更新时间："+lastUpdate);
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

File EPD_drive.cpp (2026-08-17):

#include "FS.h"
#include "EPD_drive.h"
#include "EPD_drive_gpio.h"
#include "EPD_raster.h"
#include <LittleFS.h>

unsigned char UNICODEbuffer[200];
const char* fontname="";
static const size_t GLYPH_BUFFER_SIZE=1300;
static unsigned char glyphBuffer[GLYPH_BUFFER_SIZE];

namespace {

uint8_t ReadRamXbmByte(const uint8_t* address)
{
  return *address;
}

uint8_t ReadProgmemXbmByte(const uint8_t* address)
{
  return pgm_read_byte(address);
}

void YieldDuringRasterDraw()
{
  optimistic_yield(1000UL);
}

epd_raster::BufferLayout RasterLayoutFor(epd_type type)
{
  if(type==OPM42||type==DKE42_3COLOR||type==WF42)
    return epd_raster::ROTATED_1BPP;
  if(type==WF29BZ03||type==WF32)
    return epd_raster::INTERLEAVED_2BPP;
  return epd_raster::DIRECT_1BPP;
}

} // namespace



 Duck_EPD::Duck_EPD(){
 
}


void Duck_EPD::SetFont(FONT fontindex)
{
     FontIndex=fontindex;
     switch (fontindex)
     {
     case 0:
     fontname="/font16";fontwidth=16;fontheight=16;break;
     case 1:
     fontname="/font32";fontwidth=32;fontheight=32;break;
     case 2:
     fontname="/font10";fontwidth=10;fontheight=10;break;
     case 3:
     fontname="/font12";fontwidth=12;fontheight=12;break;
     case 5:
     fontname="/font70";fontwidth=70;fontheight=70;break;
     case 6:
     fontname="/font12num";fontwidth=12;fontheight=12;break;
     case 7:
     fontname="/font24";fontwidth=24;fontheight=24;break;
     case 8:
     fontname="/font8";fontwidth=8;fontheight=8;break;
     case 9:
     fontname="/font100num";fontwidth=100;fontheight=100;break;
     case ICON_WEATHER:
     fontname="/weathericon";fontwidth=32;fontheight=32;break;
     case 12:
     fontname="/weathericon80";fontwidth=80;fontheight=80;break;
      case 13:
     fontname="/weathericon32";fontwidth=32;fontheight=32;break;
     case 14:
     fontname="/weathericon50";fontwidth=50;fontheight=50;break;
     }
  }
void Duck_EPD::DrawCircle(int x,int y,int r,bool fill)
{
  if(r<0) return;
  if(r==0)
  {
    SetPixel(x,y);
    return;
  }

  int dx=0;
  int dy=r;
  int decision=1-r;
  while(dx<=dy)
  {
    if(fill)
    {
      for(int px=x-dy;px<=x+dy;px++)
      {
        SetPixel(px,y+dx);
        if(dx!=0) SetPixel(px,y-dx);
      }
      if(dx!=dy)
      {
        for(int px=x-dx;px<=x+dx;px++)
        {
          SetPixel(px,y+dy);
          SetPixel(px,y-dy);
        }
      }
    }
    else
    {
      SetPixel(x+dx,y+dy);
      SetPixel(x-dx,y+dy);
      SetPixel(x+dx,y-dy);
      SetPixel(x-dx,y-dy);
      SetPixel(x+dy,y+dx);
      SetPixel(x-dy,y+dx);
      SetPixel(x+dy,y-dx);
      SetPixel(x-dy,y-dx);
    }

    dx++;
    if(decision<0) decision+=2*dx+1;
    else
    {
      dy--;
      decision+=2*(dx-dy)+1;
    }
  }
}

 void Duck_EPD::DrawBox(byte x,int y, int w, int h)
 {

    for(int i=x;i<x+h;i++)
  {
    DrawXline( y, y+ w-1,  i);
  }
  
 }
 void Duck_EPD::DrawEmptyBox(int x,int y,int w,int h)
{
   DrawXline(y,y+w, x);
   DrawXline(y,y+w, x+h);
   DrawYline(x,x+w, y);
   DrawYline(x,x+w, y+w);
  
}
 
 void Duck_EPD::DrawChart(int x,int y,int w, int c1, int c2, int c3, int c4, int c5,int c6)
  {
    
    int percent,sum,max_c=0;
    sum=c1+c2+c3+c4+c5+c6;
    if(sum==0) sum=1;
    max_c=max(c1,max_c);max_c=max(c2,max_c);max_c=max(c3,max_c);
    max_c=max(c4,max_c);max_c=max(c5,max_c);max_c=max(c6,max_c);
    if(max_c==0) max_c=1;
    w=w*sum/(2*max_c);
    
    SetFont(FONT12);
    DrawUTF(x,y,">0.3um");
    percent=w*c1/sum;
    DrawBox(x+1,y+41,percent,10);
    SetFont(FONT8);
    DrawUTF(x+2,y+41+percent,String(c1));
   
    SetFont(FONT12);
    DrawUTF(x+12,y,">0.5um");
    percent=w*c2/sum;
    DrawBox(x+13,y+41,percent,10);
    SetFont(FONT8);
    DrawUTF(x+14,y+41+percent,String(c2));

    SetFont(FONT12);
    DrawUTF(x+24,y,">1.0um");
    percent=w*c3/sum;
    DrawBox(x+25,y+41,percent,10);
    SetFont(FONT8);
    DrawUTF(x+26,y+41+percent,String(c3));

    SetFont(FONT12);
    DrawUTF(x+36,y,">2.5um");
    percent=w*c4/sum;
    DrawBox(x+37,y+41,percent,10);
    SetFont(FONT8);
    DrawUTF(x+38,y+41+percent,String(c4));

    SetFont(FONT12);
    DrawUTF(x+48,y,">5.0um");
    percent=w*c5/sum;
    DrawBox(x+49,y+41,percent,10);
    SetFont(FONT8);
    DrawUTF(x+50,y+41+percent,String(c5));

    SetFont(FONT12);
    DrawUTF(x+60,y,">10um");
    percent=w*c6/sum;
    DrawBox(x+61,y+41,percent,10);
    SetFont(FONT8);
    DrawUTF(x+62,y+41+percent,String(c6));
    
    
    }
 void Duck_EPD::DrawCircleChart(int x,int y,int r,int w,int c1,int c2,int c3)
 {
     int sum=c1+c2+c3;
     if(sum==0) sum=1;
        for(int i=0;i<360;i++)
      {
        SetPixel(-round(cos(M_PI*i/180)*r)+x,round(sin(M_PI*i/180)*r)+y);
        
      }
      
      for(int i=0;i<360;i++)
      {
        SetPixel(-round(cos(M_PI*i/180)*(r-w))+x,round(sin(M_PI*i/180)*(r-w))+y);
        
      }
      
      for(int i=0;i<c1*360/sum;i++)
      {
        for(int j=0;j<w;j++)
        { 
        SetPixel(-round(cos(M_PI*i/180)*(r-j))+x,round(sin(M_PI*i/180)*(r-j))+y);
        }
      }
      
      for(int i=(c1+c2)*360/sum-1;i<(c1+c2)*360/sum;i++)
      {
        
        for(int j=0;j<w;j++)
        { 
        SetPixel(-round(cos(M_PI*i/180)*(r-j))+x,round(sin(M_PI*i/180)*(r-j))+y);
        }
      }
      
      for(int i=(c1+c2)*360/sum;i<360;i+=10)
      {
        
        for(int j=0;j<w;j++)
        { 
        SetPixel(-round(cos(M_PI*i/180)*(r-j))+x,round(sin(M_PI*i/180)*(r-j))+y);
        }
      }
      
      y+=2;
      DrawBox(x-r,y+r+2,8,8);
      SetFont(FONT12);
      DrawUTF(x-r-2,y+r+12,"PM1.0");
      SetFont(FONT12);
      DrawUTF(x-r-2,y+r+12+30,String(c1));
      
      
      SetFont(FONT12);
      DrawEmptyBox(x-r+14,y+r+2,8,8);
      DrawUTF(x-r+12,y+r+12,"PM2.5");
      
      SetFont(FONT12);
      DrawUTF(x-r+12,y+r+12+30,String(c2));
      DrawEmptyBox(x-r+28,y+r+2,8,8);
      for(int i=y+r+2;i<y+r+2+8;i+=2)
        {
          DrawYline(x-r+28,x-r+28+7,i);
          }
      SetFont(FONT12);
      DrawUTF(x-r+26,y+r+12,"PM10");
      SetFont(FONT12);
      DrawUTF(x-r+26,y+r+12+30,String(c3));
  
  
  }
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

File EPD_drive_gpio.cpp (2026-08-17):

#include "EPD_drive_gpio.h"
#include <SPI.h>

/*********************************************

*********************************************/	
byte HARDWARE_SPI=0;

void SPI_Write(unsigned char value)
{     		
	//
  if(HARDWARE_SPI==0)
  {
  EPD_CLK_0;
  //delayMicroseconds(1);
  for(byte i=0;i<8;i++)
    {
     //高位在前发送方式    根据升级器件特性定
    if((value&0x80)==0x80) EPD_DIN_1
    else EPD_DIN_0;
    //delayMicroseconds(1);      //等待数据稳定  根据实际时钟调整
    EPD_CLK_1;//上升沿发送数据
    //delayMicroseconds(1);//CLK高电平保持一段时间 这个可以不需要 根据具体的spi时钟来确定
    EPD_CLK_0;; //把时钟拉低实现为下一次上升沿发送数据做准备
    value = value<<1;//发送数据的位向前移动一位
    }
  }
  else
  {
    SPI.transfer(value);
    }
}

void SPI_WriteBuffer(const unsigned char *data, size_t length)
{
  if(data==nullptr||length==0) return;
  if(HARDWARE_SPI==0)
  {
    for(size_t i=0;i<length;i++) SPI_Write(data[i]);
    return;
  }

  // EPD command payloads commonly start at buffer+1. ESP8266 writeBytes()
  // requires 32-bit alignment and raises Exception (9) otherwise, while
  // transferBytes() detects unaligned pointers and stages them safely.
  SPI.transferBytes(data,nullptr,length);
}

void SPI_WriteBufferInverted(const unsigned char *data, size_t length)
{
  if(data==nullptr||length==0) return;
  if(HARDWARE_SPI==0)
  {
    for(size_t i=0;i<length;i++) SPI_Write((unsigned char)~data[i]);
    return;
  }

  unsigned char inverted[64];
  while(length>0)
  {
    size_t chunk=length<sizeof(inverted)?length:sizeof(inverted);
    for(size_t i=0;i<chunk;i++) inverted[i]=(unsigned char)~data[i];
    SPI.transferBytes(inverted,nullptr,chunk);
    data+=chunk;
    length-=chunk;
  }
}

void SPI_WriteRepeat(unsigned char value, size_t length)
{
  if(length==0) return;
  if(HARDWARE_SPI==0)
  {
    for(size_t i=0;i<length;i++) SPI_Write(value);
    return;
  }
  SPI.writePattern(&value,1,length);
}

/*********************************************

*********************************************/	
void driver_delay_xms(unsigned long xms)	
{	
	delay(xms);
}

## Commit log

2017-06-25 switch to 000webhost
2017-06-26 add php 3dmodels
    [后支架.SLDPRT, 后支架.STL, 电纸屏外壳-对称-方形.SLDPRT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]
2017-07-07 fix bug in drawxbm add DrawXbm_P add battery bitmap
    [EPD_drive.cpp, heweather.cpp]
2017-07-08 rtc mem bug fix add char * server
    [heweather.cpp]
2017-07-15 add gerber files modify readme
2017-07-15 add bom.jpg
2017-07-15 modify 3d model
    [按钮.SLDPRT, 按钮.STL, 电纸屏外壳-对称-方形.SLDPRT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]
2017-07-19 fix bugs modify 3d models upload schematic
    [按钮.SLDPRT, 按钮.STL, 电纸屏外壳-对称-方形.SLDPRT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]
2018-05-08 2018/5/8更新天气服务器
2018-05-08 修改图片
2018-05-13 删除无用文件
2018-05-28 change voltage calculation
2018-10-15 modify to new pcb without voltage divider
    [BOM_ESP.xlsx]
2019-08-05 fix spiffs time cost
    [EPD_drive.cpp, heweather.cpp]
2026-08-17 Import latest weather station firmware
    [BOM_ESP.xlsx, 后支架.SLDPRT, 后支架.STL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]
